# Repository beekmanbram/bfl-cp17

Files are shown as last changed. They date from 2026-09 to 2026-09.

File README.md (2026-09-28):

# CP17 — Open Source Film Processor

CP17 is an open-source upgrade project for a JOBO film processor.

The goal is to reuse as much of the original JOBO mechanical hardware as possible, while replacing the original control electronics with modern, serviceable components.

## Original JOBO hardware reused

The current CP17 build reuses:

- Original JOBO drum drive mechanism
- Nidec 403.394 24 V DC motor
- Original water bath / processing tank
- Original heater element
- Original Heidolph 230/240 V circulation pump
- Original mechanical parts and enclosure where possible

The circulation pump is switched through a Finder 40.52 relay with 24 V DC coil.

## New CP17 hardware

The original electronics are replaced by:

- Raspberry Pi 4
- Waveshare 4" 800×480 HDMI display
- DFRobot DFR0601 H-bridge motor driver
- Rotary encoder
- Separate OK button
- Separate BACK button
- DS18B20 temperature sensor
- 24 V DC power supply
- New wiring, connectors and protection

The display is used without touchscreen functionality.

## 3D printed parts

3D files are included for two printed plates that adapt the original JOBO enclosure:

- **Bottom plate** — fits in the space where the original motherboard used to sit.
- **Top plate** — fits the cutout made in the JOBO cover.

Photos will be added later.

## Motor control

The original 24 V drum motor is controlled by the DFR0601.

Connections:

```
PWM  → GPIO12
INA  → GPIO6
INB  → GPIO13
```

Motor speed uses 20 kHz hardware PWM.

The motor automatically reverses direction with a short dead time between direction changes.

## Controls

```
Encoder A → GPIO16
Encoder B → GPIO20

OK button   → GPIO23 → GND
BACK button → GPIO24 → GND
```

The encoder is used only for rotation. Its push-button function is not used.

## Temperature sensor

A DS18B20 is currently used for bath-temperature monitoring.

```
VCC  → 3.3 V
GND  → GND
DATA → GPIO4
```

A 4.7 kΩ pull-up resistor is used between DATA and 3.3 V.

## Pump

The original Heidolph pump remains a 230/240 V AC device.

It is switched using:

- Finder 40.52.9.024.0000 relay
- Finder 95.05 base
- 24 V DC coil

Protective earth remains permanently connected and is never switched.

## Current status

The current prototype supports:

- Drum motor control
- Adjustable motor speed
- Automatic left/right rotation
- Bath temperature monitoring
- Physical encoder navigation
- Process timing
- Programmable development steps

## Roadmap

1. **Heater control**  
   Add automatic temperature regulation of the original JOBO heating element, including independent over-temperature protection.

2. **Temperature sensors in the development tank**  
   Add additional sensors to measure the actual chemistry temperature, not only the surrounding water bath.

3. **Automatic lift**  
   Add a motorised mechanism to automatically raise and lower the processing drum between process steps.

## Safety

CP17 combines water, 24 V electronics and 230 V mains power.

All mains wiring must be properly enclosed, fused and earthed. Protective earth must never be switched. The heater will require independent hardware over-temperature protection in addition to software control.

This project is currently a prototype and should only be reproduced by people comfortable working safely with mains-powered equipment.

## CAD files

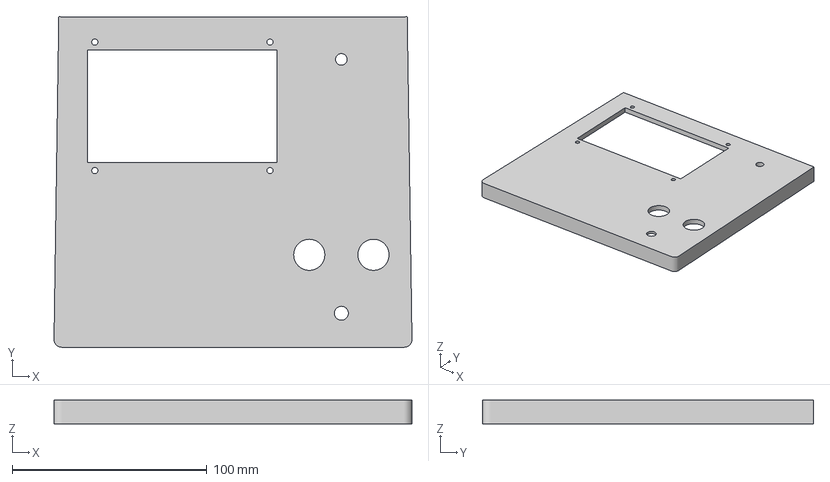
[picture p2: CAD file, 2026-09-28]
assets/3MF/CP17TopPlate.3mf
183.9 x 169.8 x 12.3 mm

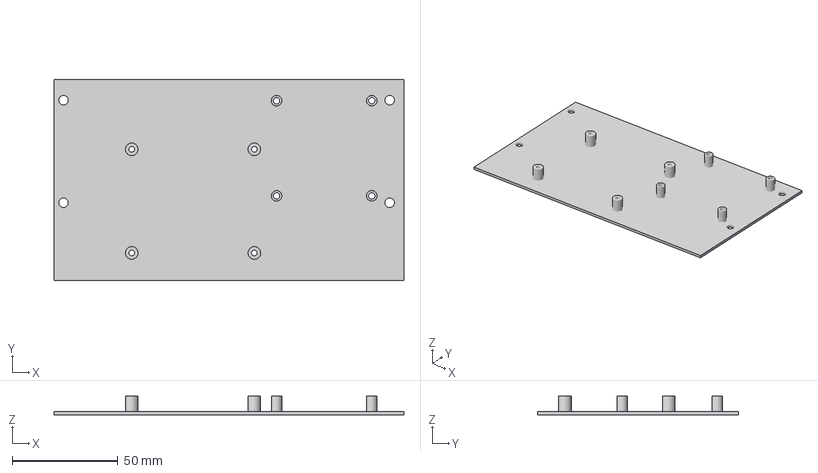
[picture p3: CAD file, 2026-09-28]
assets/3MF/CP17BottomPlate.3mf
165.5 x 95.0 x 8.80 mm

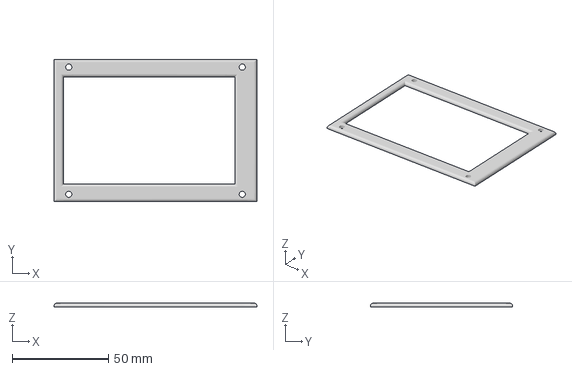
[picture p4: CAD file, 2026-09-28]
assets/3MF/CP17ScreenCover.3mf
105.3 x 73.8 x 2.00 mm

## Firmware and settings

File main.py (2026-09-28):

import copy
import json
import os
import shutil
import subprocess
import sys
import threading
import time
import tkinter as tk
from pathlib import Path

try:
    import pwd
except ImportError:
    pwd = None

try:
    from gpiozero import Button, DigitalInputDevice, DigitalOutputDevice
    HAS_GPIO = True
except ImportError:
    HAS_GPIO = False
    Button = None


# ============================================================
# JOBO FILM PROCESSOR
#
# DFR0601
# PWM1 -> GPIO12  (physical 32)  hardware PWM 20 kHz
# INA1 -> GPIO6   (physical 31)
# INB1 -> GPIO13  (physical 33)
#
# Encoder, rotation only
# A -> GPIO16
# B -> GPIO20
# GPIO21 is unused. The encoder push button is not used.
#
# Separate buttons to GND, internal pull-up
# OK   -> GPIO23
# BACK -> GPIO24
#
# DS18B20 DATA -> GPIO4
# Screen 800x480, no touch
# ============================================================


INA_GPIO = 6
INB_GPIO = 13
ENCODER_A_GPIO = 16
ENCODER_B_GPIO = 20
OK_GPIO = 23
BACK_GPIO = 24

PWM_PERIOD_NS = 50_000
PWM_CHANNEL = 0

WIDTH = 800
HEIGHT = 480

BG = "#0d0d0d"
TEXT = "#f2f2f2"
MUTED = "#8a8a8a"
ACCENT = "#e0a800"
GREEN = "#7dcea0"
RED = "#e06c6c"
ORANGE = "#ef6c00"
TRACK = "#1c1c1c"

FONT = "DejaVu Sans"
MONO = "DejaVu Sans Mono"

ENCODER_DETENT_TICKS = 4
QUAD_DELTA = {
    0b0001: 1,
    0b0111: 1,
    0b1110: 1,
    0b1000: 1,
    0b0010: -1,
    0b1011: -1,
    0b1101: -1,
    0b0100: -1,
}


class DummyDigitalOutputDevice:
    def __init__(self, pin, initial_value=False):
        self.pin = pin
        self.value = bool(initial_value)

    def on(self):
        self.value = True

    def off(self):
        self.value = False

    def close(self):
        pass


class DummyInputDevice:
    value = False
    is_pressed = False
    when_activated = None
    when_deactivated = None
    when_pressed = None

    def __init__(self, *args, **kwargs):
        pass

    def close(self):
        pass


class NavRow:
    def __init__(self, widget, action, text):
        self.widget = widget
        self.action = action
        self.text = text


def get_real_home():
    sudo_user = os.environ.get("SUDO_USER")
    if sudo_user and pwd is not None:
        try:
            return Path(pwd.getpwnam(sudo_user).pw_dir)
        except Exception:
            pass
    return Path.home()


def is_raspberry_pi():
    model = Path("/sys/firmware/devicetree/base/model")
    if model.exists():
        try:
            return b"raspberry" in model.read_bytes().lower()
        except Exception:
            pass
    return Path("/sys/class/gpio").exists()


HOME = get_real_home()
RECIPES_FILE = HOME / "jobo-recipes.json"
SETTINGS_FILE = HOME / "jobo-settings.json"
ON_PI = is_raspberry_pi()


DEFAULT_SETTINGS = {
    "speed": 30,
    "left_seconds": 10.0,
    "right_seconds": 10.0,
    "direction_delay_ms": 50,
    "encoder_step": 1,
}

DEFAULT_RECIPES = [
    {
        "name": "B&W example",
        "speed": 30,
        "left_seconds": 10.0,
        "right_seconds": 10.0,
        "steps": [
            {"name": "Develop", "seconds": 300, "motor": True},
            {"name": "Stop", "seconds": 30, "motor": True},
            {"name": "Fix", "seconds": 300, "motor": True},
            {"name": "Wash", "seconds": 60, "motor": True},
            {"name": "Wash", "seconds": 60, "motor": True},
        ],
    }
]

STEP_NAMES = [
    "Prewash",
    "Develop",
    "Stop",
    "Fix",
    "Bleach",
    "Blix",
    "Wash",
    "Stabilizer",
    "Final rinse",
    "Dry",
    "Custom",
]


def chown_if_sudo(filename):
    sudo_user = os.environ.get("SUDO_USER")
    if not sudo_user or pwd is None:
        return
    try:
        user = pwd.getpwnam(sudo_user)
        os.chown(filename, user.pw_uid, user.pw_gid)
    except Exception:
        pass


def load_json(filename, default):
    try:
        if filename.exists():
            with open(filename, "r", encoding="utf-8") as handle:
                return json.load(handle)
    except Exception:
        pass
    return copy.deepcopy(default)


def save_json(filename, data):
    filename = Path(filename)
    tmp = filename.with_name(filename.name + ".tmp")
    try:
        with open(tmp, "w", encoding="utf-8") as handle:
            json.dump(data, handle, indent=4)
            handle.flush()
            os.fsync(handle.fileno())
        os.replace(tmp, filename)
        chown_if_sudo(filename)
    except Exception:
        try:
            if tmp.exists():
                tmp.unlink()
        except Exception:
            pass
        raise


def clamp(value, minimum, maximum):
    return max(minimum, min(value, maximum))


def snap_to_step(value, minimum, maximum, step):
    value = float(value)
    if step:
        steps = round((value - minimum) / step)
        value = minimum + steps * step
    if isinstance(step, int) and step >= 1:
        value = int(round(value))
    else:
        value = round(value, 4)
    return clamp(value, minimum, maximum)


def normalize_settings(data):
    settings_data = copy.deepcopy(DEFAULT_SETTINGS)
    if not isinstance(data, dict):
        return settings_data
    try:
        settings_data["speed"] = int(clamp(int(data.get("speed", 30)), 0, 100))
    except (TypeError, ValueError):
        pass
    try:
        settings_data["left_seconds"] = float(
            clamp(float(data.get("left_seconds", 10.0)), 0.5, 60)
        )
    except (TypeError, ValueError):
        pass
    try:
        settings_data["right_seconds"] = float(
            clamp(float(data.get("right_seconds", 10.0)), 0.5, 60)
        )
    except (TypeError, ValueError):
        pass
    try:
        settings_data["direction_delay_ms"] = int(
            clamp(int(data.get("direction_delay_ms", 50)), 20, 500)
        )
    except (TypeError, ValueError):
        pass
    try:
        settings_data["encoder_step"] = int(
            clamp(int(data.get("encoder_step", 1)), 1, 10)
        )
    except (TypeError, ValueError):
        pass
    return settings_data


def normalize_step(step):
    if not isinstance(step, dict):
        return {"name": "Wash", "seconds": 60, "motor": True}
    name = str(step.get("name") or "Custom")
    try:
        seconds = int(clamp(int(step.get("seconds", 60)), 1, 3600))
    except (TypeError, ValueError):
        seconds = 60
    return {"name": name, "seconds": seconds, "motor": bool(step.get("motor", True))}


def normalize_recipe(recipe, fallback_name="Process"):
    if not isinstance(recipe, dict):
        recipe = {}
    steps = recipe.get("steps")
    if not isinstance(steps, list) or not steps:
        steps = [{"name": "Develop", "seconds": 300, "motor": True}]
    try:
        speed = int(clamp(int(recipe.get("speed", settings["speed"])), 0, 100))
    except (TypeError, ValueError):
        speed = settings["speed"]
    try:
        left_seconds = float(
            clamp(float(recipe.get("left_seconds", settings["left_seconds"])), 0.5, 60)
        )
    except (TypeError, ValueError):
        left_seconds = settings["left_seconds"]
    try:
        right_seconds = float(
            clamp(float(recipe.get("right_seconds", settings["right_seconds"])), 0.5, 60)
        )
    except (TypeError, ValueError):
        right_seconds = settings["right_seconds"]
    return {
        "name": str(recipe.get("name") or fallback_name),
        "speed": speed,
        "left_seconds": round(left_seconds, 1),
        "right_seconds": round(right_seconds, 1),
        "steps": [normalize_step(step) for step in steps],
    }


def normalize_recipes(data):
    if not isinstance(data, list) or not data:
        return copy.deepcopy(DEFAULT_RECIPES)
    recipes_data = [
        normalize_recipe(recipe, f"Process {index + 1}")
        for index, recipe in enumerate(data)
    ]
    return recipes_data or copy.deepcopy(DEFAULT_RECIPES)


settings = normalize_settings(load_json(SETTINGS_FILE, DEFAULT_SETTINGS))
recipes = normalize_recipes(load_json(RECIPES_FILE, DEFAULT_RECIPES))


class HardwarePWM:
    def __init__(self, channel=0, period_ns=50_000):
        self.channel = channel
        self.period_ns = period_ns
        self._last_duty = None
        self.chip = self.find_pwm_chip()
        self.pwm = self.chip / f"pwm{channel}"
        self.export()
        self.enable = self.pwm / "enable"
        self.period = self.pwm / "period"
        self.duty = self.pwm / "duty_cycle"
        self.write(self.enable, 0)
        self.write(self.duty, 0)
        self.write(self.period, self.period_ns)
        self.write(self.duty, 0)
        self.write(self.enable, 1)
        self._last_duty = 0

    def find_pwm_chip(self):
        chips = sorted(Path("/sys/class/pwm").glob("pwmchip*"))
        for chip in chips:
            try:
                npwm = int((chip / "npwm").read_text().strip())
                if npwm > self.channel:
                    return chip
            except Exception:
                continue
        raise RuntimeError(
            "Hardware PWM not found. Check dtoverlay=pwm,pin=12,func=4"
        )

    def export(self):
        if self.pwm.exists():
            return
        try:
            self.write(self.chip / "export", self.channel)
        except Exception:
            pass
        for _ in range(50):
            if self.pwm.exists():
                return
            time.sleep(0.02)
        raise RuntimeError("PWM channel could not be created.")

    @staticmethod
    def write(path, value):
        payload = str(value)
        last_error = None
        for _ in range(5):
            try:
                with open(path, "w") as handle:
                    handle.write(payload)
                return
            except OSError as error:
                last_error = error
                time.sleep(0.01)
        if last_error is not None:
            raise last_error

    def set_percent(self, percent):
        percent = clamp(float(percent), 0.0, 100.0)
        duty = int(clamp(self.period_ns * percent / 100.0, 0, self.period_ns))
        if duty == self._last_duty:
            return
        self.write(self.duty, duty)
        self._last_duty = duty

    def stop(self):
        self.set_percent(0)

    def close(self):
        try:
            self.stop()
        except Exception:
            pass
        try:
            self.write(self.enable, 0)
        except Exception:
            pass


class DummyPWM:
    def set_percent(self, percent):
        pass

    def stop(self):
        pass

    def close(self):
        pass


class MotorController:
    def __init__(self, simulated=False):
        self.simulated = simulated
        pin_class = DummyDigitalOutputDevice if simulated else DigitalOutputDevice
        self.ina = pin_class(INA_GPIO, initial_value=False)
        self.inb = pin_class(INB_GPIO, initial_value=False)
        self.pwm = DummyPWM() if simulated else HardwarePWM(PWM_CHANNEL, PWM_PERIOD_NS)
        self.running = False
        self.speed = 0
        self.direction = "LEFT"
        self.switching = False
        self._switch_token = 0
        self._switch_after = None
        self._restore_after = None
        self._pwm_after = None

    def left(self):
        self.ina.off()
        self.inb.on()
        self.direction = "LEFT"

    def right(self):
        self.ina.on()
        self.inb.off()
        self.direction = "RIGHT"

    def coast(self):
        self.ina.off()
        self.inb.off()

    def _cancel_after(self, attr):
        handle = getattr(self, attr)
        if handle is not None:
            try:
                root.after_cancel(handle)
            except Exception:
                pass
            setattr(self, attr, None)

    def _cancel_pending(self):
        self._switch_token += 1
        self.switching = False
        self._cancel_after("_switch_after")
        self._cancel_after("_restore_after")
        self._cancel_after("_pwm_after")

    def _apply_direction(self, direction=None):
        chosen = direction or self.direction or "LEFT"
        if chosen == "LEFT":
            self.left()
        else:
            self.right()

    def start(self, speed, direction=None):
        self._cancel_pending()
        self._apply_direction(direction)
        self.speed = int(clamp(int(speed), 0, 100))
        self.running = True
        self.pwm.set_percent(self.speed)

    def stop(self):
        self._cancel_pending()
        self.running = False
        try:
            self.pwm.stop()
        except Exception:
            pass
        self.coast()

    def set_speed(self, speed):
        self.speed = int(clamp(int(speed), 0, 100))
        if not self.running:
            return
        if self._pwm_after is not None:
            return
        self._pwm_after = root.after(5, self._flush_pwm)

    def _flush_pwm(self):
        self._pwm_after = None
        if self.running and not self.switching:
            try:
                self.pwm.set_percent(self.speed)
            except Exception:
                pass

    def switch_direction(self, direction, finished=None):
        if self.switching or not self.running:
            return
        self.switching = True
        self._switch_token += 1
        token = self._switch_token
        delay = int(settings["direction_delay_ms"])
        try:
            self.pwm.stop()
        except Exception:
            pass

        def restore():
            self._restore_after = None
            if token != self._switch_token:
                return
            if self.running:
                try:
                    self.pwm.set_percent(self.speed)
                except Exception:
                    pass
            self.switching = False
            if finished:
                finished()

        def change():
            self._switch_after = None
            if token != self._switch_token or not self.running:
                self.switching = False
                return
            self._apply_direction(direction)
            self._restore_after = root.after(10, restore)

        self._switch_after = root.after(max(1, delay), change)

    def close(self):
        try:
            self.stop()
        except Exception:
            pass
        try:
            self.pwm.close()
        except Exception:
            pass
        try:
            self.ina.close()
            self.inb.close()
        except Exception:
            pass


root = None
content = None
temp_label = None
list_canvas = None
list_inner = None
list_window = None
motor = None
simulated_hardware = False
hardware_error = None

shutdown_event = threading.Event()
temp_thread = None
after_ids = {}

current_screen = "menu"
nav_items = []
nav_index = 0

adjust_mode = False
adjust_value = 0
adjust_min = 0
adjust_max = 100
adjust_step = 1
adjust_callback = None
adjust_cancel_callback = None
adjust_formatter = None
adjust_label = None

choice_mode = False
choice_values = []
choice_callback = None
choice_cancel_callback = None

encoder_lock = threading.Lock()
pending_encoder_steps = 0
encoder_flush_scheduled = False
encoder_quad_state = 0
encoder_quad_accum = 0

manual_active = False
manual_next_switch = None
manual_speed = settings["speed"]
manual_motor_label = None
manual_rows = {}

settings_snapshot = None

current_recipe_index = 0
editor_recipe_index = 0
editor_step_index = 0

run_recipe = None
run_step_index = 0
run_active = False
run_paused = False
run_step_finished = False
run_remaining = 0.0
run_step_total = 1.0
run_last_tick = 0.0
run_next_direction = None
run_switch_remaining = None

process_timer_label = None
process_motor_label = None
process_status_label = None
progress_canvas = None
pause_row = None

encoder_a = None
encoder_b = None
ok_button = None
back_button = None


def cancel_after(key):
    handle = after_ids.pop(key, None)
    if handle is not None:
        try:
            root.after_cancel(handle)
        except Exception:
            pass


def schedule(key, delay_ms, callback):
    cancel_after(key)
    after_ids[key] = root.after(delay_ms, callback)


def safe_config(widget, **kwargs):
    try:
        if widget is not None and widget.winfo_exists():
            widget.config(**kwargs)
            return True
    except tk.TclError:
        pass
    return False


def stop_all_activity():
    global manual_active, run_active, run_paused, run_step_finished
    global run_next_direction, run_switch_remaining, manual_next_switch

    manual_active = False
    run_active = False
    run_paused = False
    run_step_finished = False
    run_next_direction = None
    run_switch_remaining = None
    manual_next_switch = None
    cancel_after("manual_tick")
    cancel_after("process_tick")
    if motor is not None:
        motor.stop()


def field(label, value):
    return f"{label:<18}{value}"


def format_time(seconds):
    seconds = max(0, int(round(seconds)))
    return f"{seconds // 60:02d}:{seconds % 60:02d}"


def format_percent(value):
    return f"{int(value)}%"


def format_seconds(value):
    return f"{float(value):.1f}s"


def format_ms(value):
    return f"{int(value)} ms"


def read_temperature():
    base = Path("/sys/bus/w1/devices")
    if not base.exists():
        return None
    sensors = list(base.glob("28-*"))
    if not sensors:
        return None
    try:
        text = (sensors[0] / "w1_slave").read_text()
        if "YES" not in text:
            return None
        return float(text.split("t=")[-1]) / 1000.0
    except Exception:
        return None


def apply_temperature_text(text):
    safe_config(temp_label, text=text)


def temperature_loop():
    while not shutdown_event.is_set():
        temp = read_temperature()
        text = "Temp. --.-°C" if temp is None else f"Temp. {temp:.1f}°C"
        try:
            if root is not None:
                root.after(0, apply_temperature_text, text)
        except Exception:
            break
        shutdown_event.wait(1.5)


def clear_screen():
    global nav_items, nav_index, list_canvas, list_inner, list_window
    for widget in content.winfo_children():
        widget.destroy()
    nav_items = []
    nav_index = 0
    list_canvas = None
    list_inner = None
    list_window = None


def add_title(text, size=26):
    tk.Label(
        content,
        text=text,
        font=(FONT, size, "bold"),
        bg=BG,
        fg=TEXT,
        anchor="w",
    ).pack(fill=tk.X, padx=36, pady=(10, 4))


def add_info(text, size=16, color=MUTED):
    label = tk.Label(
        content,
        text=text,
        font=(FONT, size),
        bg=BG,
        fg=color,
        anchor="w",
        justify=tk.LEFT,
    )
    label.pack(fill=tk.X, padx=40, pady=1)
    return label


def begin_rows():
    global list_canvas, list_inner, list_window
    list_canvas = tk.Canvas(content, bg=BG, highlightthickness=0, bd=0)
    list_canvas.pack(fill=tk.BOTH, expand=True, pady=(6, 8))
    list_inner = tk.Frame(list_canvas, bg=BG)
    list_window = list_canvas.create_window((0, 0), window=list_inner, anchor="nw")

    def sync(_event=None):
        if list_canvas is None or list_inner is None:
            return
        try:
            list_canvas.configure(scrollregion=list_canvas.bbox("all"))
            list_canvas.itemconfigure(list_window, width=list_canvas.winfo_width())
        except tk.TclError:
            pass

    list_inner.bind("<Configure>", sync)
    list_canvas.bind("<Configure>", sync)
    return list_inner


def add_row(parent, text, action, size=20):
    label = tk.Label(
        parent,
        text="  " + text,
        font=(MONO, size),
        bg=BG,
        fg=TEXT,
        anchor="w",
        padx=32,
    )
    label.pack(fill=tk.X, pady=3)
    return NavRow(label, action, text)


def set_navigation(items, selected=0):
    global nav_items, nav_index
    nav_items = [item for item in items if item is not None]
    if not nav_items:
        nav_index = 0
        return
    nav_index = int(clamp(selected, 0, len(nav_items) - 1))
    update_navigation()


def update_navigation():
    for index, row in enumerate(nav_items):
        selected = index == nav_index
        prefix = "> " if selected else "  "
        safe_config(
            row.widget,
            text=prefix + row.text,
            fg=ACCENT if selected else TEXT,
        )
    reveal_selection()


def reveal_selection():
    if list_canvas is None or not nav_items:
        return
    widget = nav_items[nav_index].widget
    try:
        list_canvas.update_idletasks()
        inner_h = max(1, list_inner.winfo_height())
        view_h = max(1, list_canvas.winfo_height())
        if inner_h <= view_h:
            list_canvas.yview_moveto(0)
            return
        target = max(0, widget.winfo_y() - (view_h * 0.35))
        list_canvas.yview_moveto(target / inner_h)
    except tk.TclError:
        pass


def nav_move(steps):
    global nav_index
    if not nav_items or not steps:
        return
    nav_index = (nav_index + int(steps)) % len(nav_items)
    update_navigation()


def nav_activate():
    if not nav_items:
        return
    action = nav_items[nav_index].action
    if action:
        action()
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

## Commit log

2026-09-28 fix shutdown with now
    [main.py]
2026-09-28 fix no sudo password shutdown
    [main.py]
2026-09-28 3d files
    [CP17BottomPlate.3mf, CP17ScreenCover.3mf, CP17TopPlate.3mf]
